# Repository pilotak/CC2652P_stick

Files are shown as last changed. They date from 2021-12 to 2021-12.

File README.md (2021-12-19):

# CC2652P USB stick
CC2652P based Zigbee coordinator/router

## Flashing
- download [cc2538-bsl](https://github.com/JelmerT/cc2538-bsl) (you may need to install Python and/or other dependecies listed there)
- download [firmware](https://github.com/Koenkk/Z-Stack-firmware)
- run (change COM port to suit yours and specify location of downloaded FW)
```
python cc2538-bsl.py -p COM8 -w ./CC1352P2_CC2652P_other_router_20210128.hex
```

### BOM
| Qty | Value | Package | Component |
|:---:| --- | ----- | --- |
| 2 | 1uF/10V | 0805 | Ceramic capacitor |
| 1 | 100n | 0805 | Ceramic capacitor |
| 1 | 10n | 0805 | Ceramic capacitor |
| 1 | CH340C | SO16 | USB to Serial |
| 1 | USB A | | USB Connector |
| 1 | Red LED | 0603 | |
| 1 | Green LED | 0603 | |
| 1 | 100R | 0805 | Resistor |
| 1 | 1K | 0805 | Resistor |
| 1 | 820R | 0805 | Resistor |
| 1 | 10K | 0805 | Resistor |
| 1 | SMD button |  |  |
| 1 | MCP1802T-3302I/OT | SOT23-5 | LDO regulator |
| 1 | EBYTE-E72 |  | CC2652P based wireless module |
| 1 | 1551USB2 |  | USB enclosure by Hammond |

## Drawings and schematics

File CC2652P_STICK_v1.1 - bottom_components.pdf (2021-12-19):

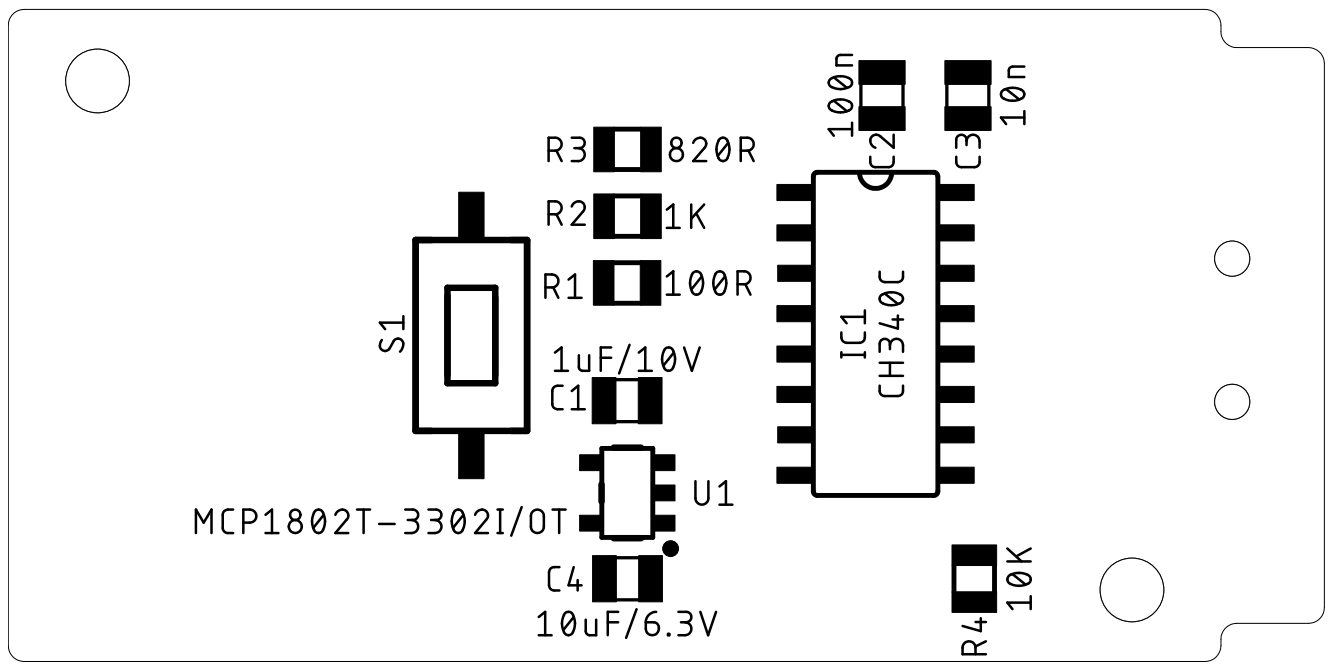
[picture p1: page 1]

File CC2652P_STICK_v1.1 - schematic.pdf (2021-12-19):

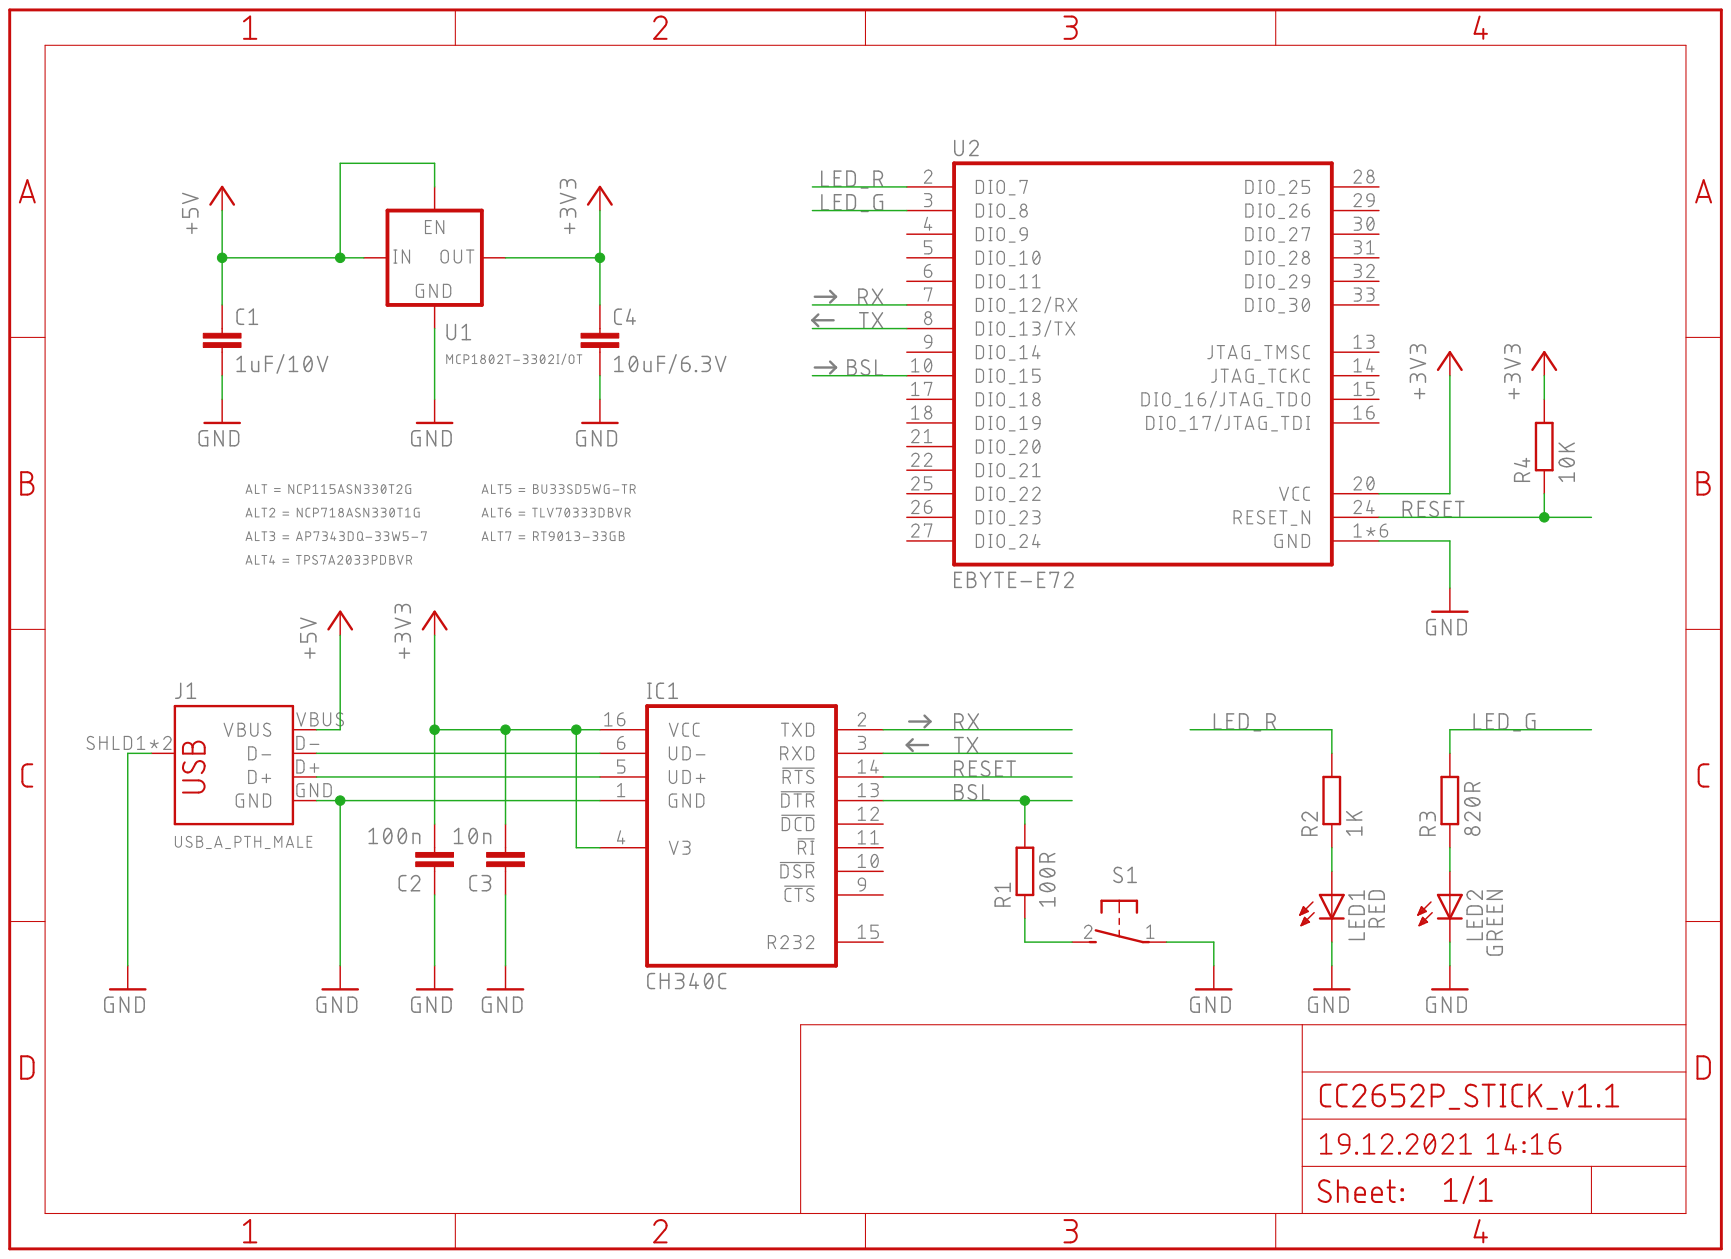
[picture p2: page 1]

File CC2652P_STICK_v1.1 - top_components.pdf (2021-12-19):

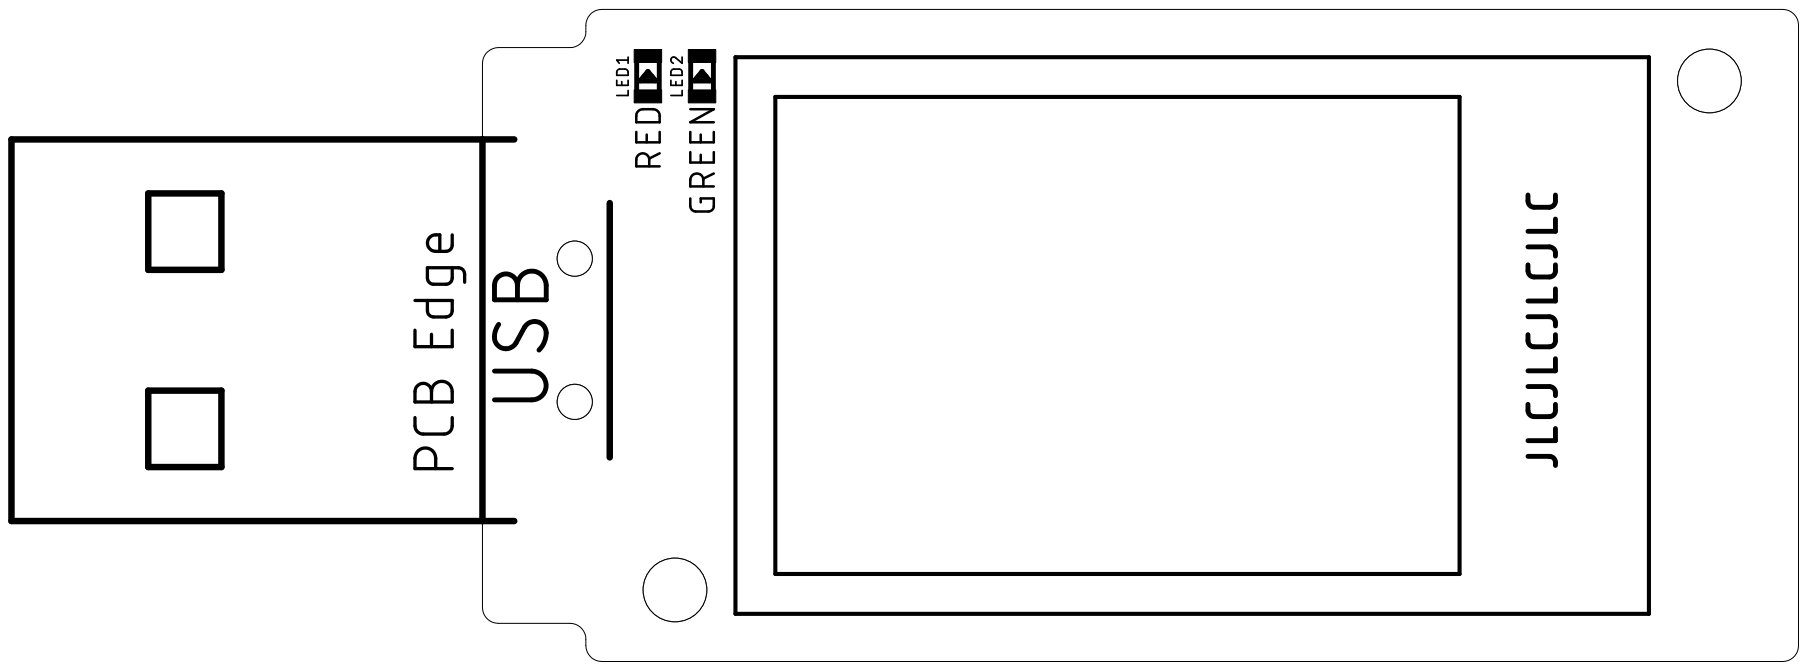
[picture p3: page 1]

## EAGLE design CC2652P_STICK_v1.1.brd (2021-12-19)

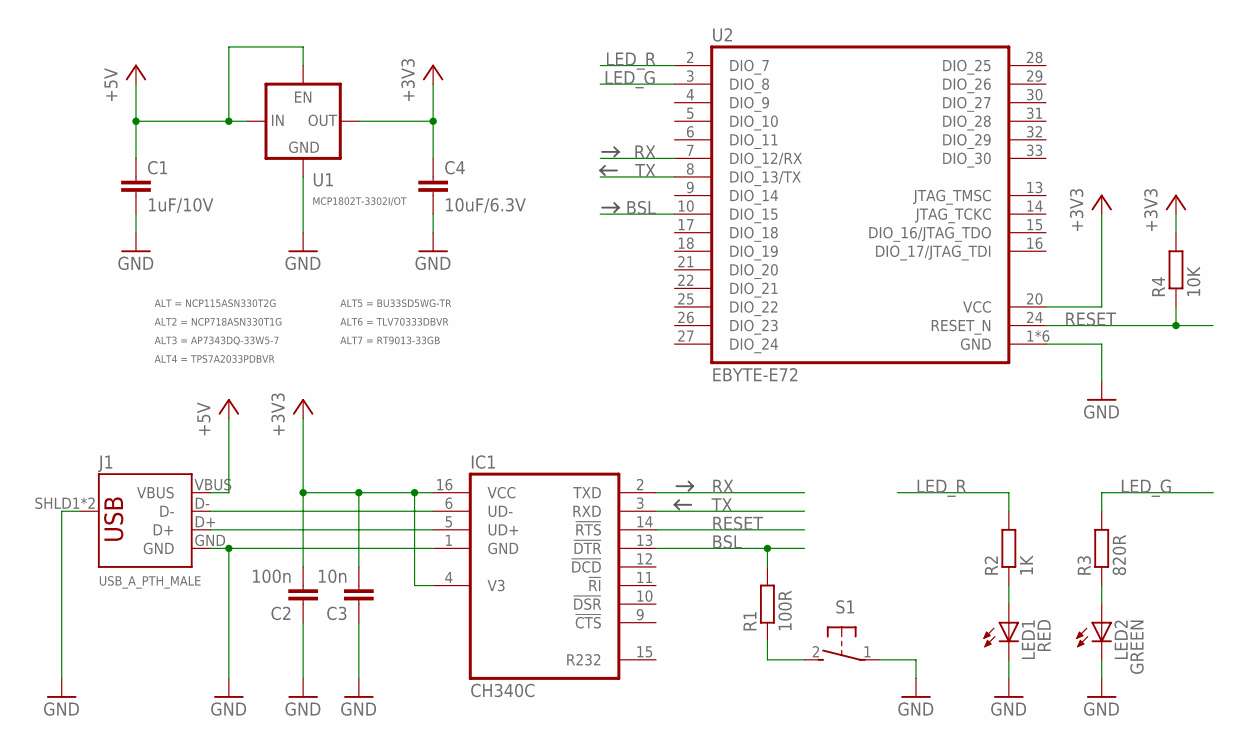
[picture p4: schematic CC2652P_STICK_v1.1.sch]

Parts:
C1: 1uF/10V; C0805
C2: 100n; C0805
C3: 10n; C0805
C4: 10uF/6.3V; C0805
IC1: CH340C; SO16
J1: USB_A_PTH_MALE; USB-A-H
LED1: RED; LED0603
LED2: GREEN; LED0603
R1: 100R; R0805
R2: 1K; R0805
R3: 820R; R0805
R4: 10K; R0805
S1: DTSM-3
U1: MCP1802T-3302I/OT; SOT23-5
U2: EBYTE-E72

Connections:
+3V3: C2.2, C3.2, C4.1, IC1.4 (V3), IC1.16 (VCC), R4.2, U1.5 (VOUT), U2.20 (VCC)
+5V: C1.1, J1.VBUS, U1.1 (VIN), U1.3 (EN)
BSL: IC1.13 (!DTR), R1.2, U2.10 (DIO_15)
DN: IC1.6 (UD-), J1.D-
DP: IC1.5 (UD+), J1.D+
GND: C1.2, C2.1, C3.1, C4.2, IC1.1 (GND), J1.GND, J1.SHLD1 (SHIELD), J1.SHLD2 (SHIELD), LED1.C, LED2.C, S1.1, U1.2 (GND), U2.1 (GND), U2.11 (GND), U2.12 (GND), U2.19 (GND), U2.23 (GND), U2.34 (GND)
LED_G: R3.2, U2.3 (DIO_8)
LED_R: R2.2, U2.2 (DIO_7)
unnamed: LED2.A, R3.1
unnamed: LED1.A, R2.1
unnamed: R1.1, S1.2
RESET: IC1.14 (!RTS), R4.1, U2.24 (RESET_N)
RX: IC1.2 (TXD), U2.7 (DIO_12/RX)
TX: IC1.3 (RXD), U2.8 (DIO_13/TX)

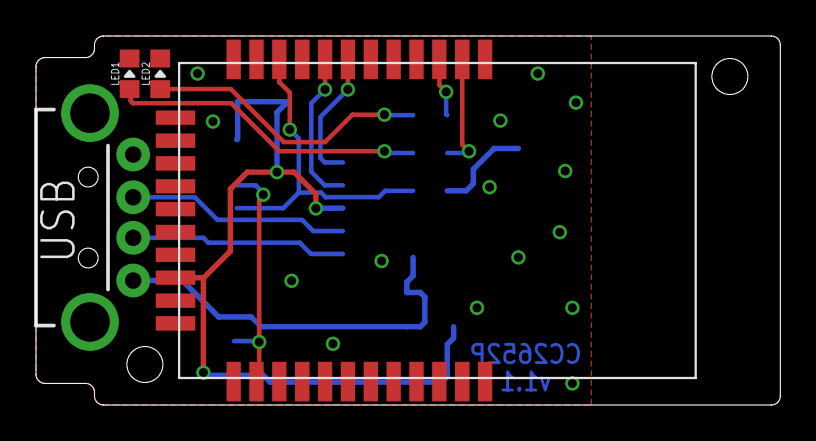
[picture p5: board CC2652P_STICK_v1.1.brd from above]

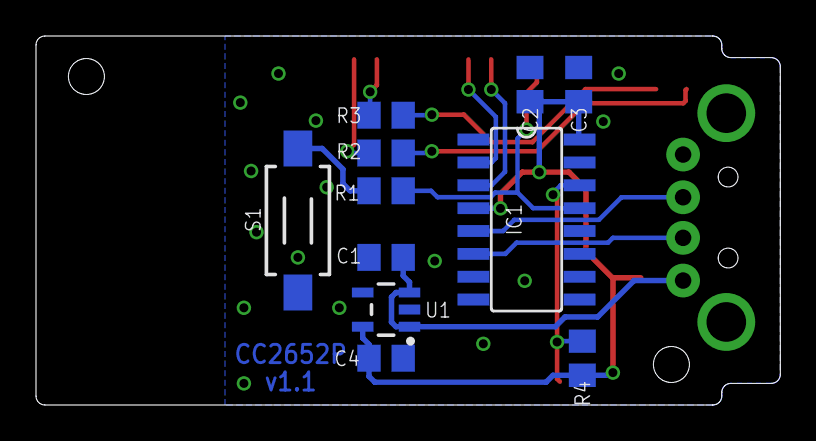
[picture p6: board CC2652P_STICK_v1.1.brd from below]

Board: 2 copper layers, 41.4 x 20.5 mm, 15 parts (11 on the bottom side), 14 nets.

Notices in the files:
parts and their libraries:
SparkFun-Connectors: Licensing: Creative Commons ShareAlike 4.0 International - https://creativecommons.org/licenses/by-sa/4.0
